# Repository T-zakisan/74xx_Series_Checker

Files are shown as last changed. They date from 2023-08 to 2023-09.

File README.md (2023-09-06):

# 74xx Series Checker
汎用ロジックIC（以降74シリーズ）の刻印が見えづらくて、どの74シリーズか判別がつかなくなることがある。  
場合によっては、配線ミスや足の欠落などにより動作しない場合もある。  
（※コレはこれで、動作不良部位を見出す訓練にもなるが、初期ではシナリオ通りの動作であった方が良い）  
それらのトラブルを回避し、刻印を読むことを目的とせず、実習を通じて論理的思考に意識を寄せたい。  

そこで、74シリーズの判定と各ビットの動作是非を表示するガジェットをArduino MicroProで作製していた。  
しかし、Arduino系は、コスト高・ソースコードの管理がメンドい（こういうところで管理すればいいだけだが、作った勢いで満足してしまいソースコードをなくしてしまった）ため、**RP2040**系に移植することにした。  
また、今回使用したマイコンの端子は、**USB Type-C**であることから、将来的なケーブル問題の懸念も解消しやすいと思う。



## 動作しているの様子
７４シリーズをＩＣソケットにセットし、マイコンのリセットボタンを押すことでロジックＩＣの種類がＬＣＤに表示される（NANDの場合：`00 NAND`）。  
機能しているビットは、そのナンバーが表示される（1-4番目のビットが機能している場合：`1234__/4`）。  
あるビットが機能していない場合や足が折れている場合は、`x`が表示される（3番目が機能していない場合：`12x4__/4`）。
対応していないロジックＩＣやロジックＩＣをセットしていない場合は、`UnKnown！`と表示される。  

https://github.com/T-zakisan/74xx_Series_Checker/assets/43605763/a2278c76-78e3-49d2-b7b0-828096098356

## 判定に対応しているロジックＩＣ
ここで対応する74シリーズは、以下とものとしている。  
また、14ピンに限る。
| 型番 | ロジック名 |
|:----:|----|
| 7400 | NAND |
| 7402 | NOR |
| 7404 | NOT |
| 7408 | AND |
| 7432 | OR |
| 7486 | Ex-OR |

## 表示の意味
液晶ディスプレイに以下の内容を表示する

| 項目名 | 例 |
|:----:|:----|
| 型番下２桁 | 74xxのxxの部分　NANDなら**00** |
| ロジック名 | NAND、ORなど |
| 可動ビット | NOTなら1-6、それ以外なら1-4　（不良はx） |
| 総ビット数 | NOTなら6、それ以外なら4 |

# 作成方法
## パーツリスト
| パーツ名 | 備考 |
|:----|:----|
| [RP2040マイコンボードキット](https://akizukidenshi.com/catalog/g/gK-17542/) | [CirCuitPythonのファームウェアを書き込むこと](https://circuitpython.org/board/raspberry_pi_pico/) |
| [ゼロプレッシャーＩＣソケット 14P](https://akizukidenshi.com/catalog/g/gP-12073/) ||
| [Ｉ２Ｃ接続小型ＬＣＤモジュール（8×2行）ピッチ変換キット](https://akizukidenshi.com/catalog/g/gK-06795/) ||
| [角型ランド両面スルーホールガラスコンポジット・ユニバーサル基板 Cタイプ(72×47mm)](https://akizukidenshi.com/catalog/g/gP-09747/) ||
| ネジ　M3xN10mm | 4 |
| ナット　M3 | 4 |
| ネジ　M2x10mm | 2 |
| ナット　M2 | 2 |
| アクリル板 | 2mm |
| ジャンパ線 | 適当 |

## アサイン
下表のアサインに従い配線を施す。  
ちなみに配線の取り回しの関係からGPIOで`GND`や`Vcc(3.3V)`を得ているが、マイコンオンボード上のソレを利用して問題ない。  
独自にアサインを変更した場合は、上記ソースコード(`code.py`)を書き換えること！

| マイコン端子 | パーツ端子 | 備考|
|:----:|:----|:----|
| 0 | LCD (Vcc) |  |
| 1 | LCD, Sw (GND) |  |
| 2 | 74シリーズ (4) | In / Output |
| 3 | 74シリーズ (1) | In / Output |
| 4 | 74シリーズ (2) | In / Output |
| 5 | 74シリーズ (3) | In / Output |
| 6 | 74シリーズ (14) | Vcc |
| 7 | 74シリーズ (13) | In / Output |
| 8 | 74シリーズ (12) | In / Output |
| 9 | 74シリーズ (11) | In / Output |
| 10 | 74シリーズ (10) | In / Output |
| 11 | 74シリーズ (9) | In / Output |
| 12 | 74シリーズ (8) | In / Output |
| 13 | 74シリーズ (5) | In / Output |
| 14 | 74シリーズ (6) | In / Output |
| 15 | 74シリーズ (7) | GND |
| 26 | LCD (SDA) |  |
| 27 | LCD (SCL) |  |
| 28 | SW (+) |  |



## 必須ライブラリ
| ライブラリ名 | 備考|
|:----|:----|
| st7032i.py | [LCDで使用](https://gist.github.com/boochow/6ffd0c939abbcc1a9c62bf6ab6b60cef#file-st7032i-py) |

## プログラム
1. マイコンに[ファームウェア](https://circuitpython.org/board/raspberry_pi_pico/)を書き込む
   - Pico用のファームウェアで問題ない
   - 書き込み方は、[ココ](https://learn.adafruit.com/welcome-to-circuitpython/installing-circuitpython)を見るか、`CirCuitPython ファームウェア 書き込み方法` でググると日本語のドキュメントがヒットする
2. 上記のライブラリ`st7032i.py`を`マイコン内の/lib`に保存
3. 上記の `code.py` をマイコンに保存

## ケース
必要に応じて、上記の3Dプリンタ用のファイル(.STL)とレーザー加工用ファイル(.DXF、.SVG)を用いてケースを作成する

| ファイル種 | 備考|
|:----|:----|
| STL | ３Ｄプリンタで印刷 |
| DXF | レーザー加工機でアクリル板（２ｍｍ）を切断・彫刻 |
| SVG | 　〃　 |

3Dモデル

# 使用方法
1. ＩＣソケットのバーを上げる
2. ＩＣソケットに７４シリーズを装着
   - ＩＣソケットのバー側が**ロジックＩＣの欠け**のある向きにすること！
3. ボタンを押す　　以上

# 反省
当初マイコンオンボードにある***RUN***ボタンを押すことで、ロジックＩＣの判定を行っていた。  
しかし、CirCuitPythonは起動にやや時間がかかるため、***RUN***ボタンを押してから、ロジックＩＣの判定までにタイムラグがあった。  
そこで、別途タクトスイッチを追加し、そのスイッチを押したときに判定することで、再起動を回避した。  
また、スイッチを押すまでは、[Alarm](**https://docs.circuitpython.org/en/latest/shared-bindings/alarm/index.html**)(**light sleep**)を利用することでプログラムを停止させ、消費電力を低減させている。  

念のため、それぞれの動作方法によるソースコードやケースデータ(.STL, .SVG)を置いておく。   
ディレクトリ名は、以下の通りとする。

| 動作方法 | ディレクトリ名 |
|:----|:----|
| Runスイッチ | RunSw |
| タクトスイッチ | ReLoadSw |

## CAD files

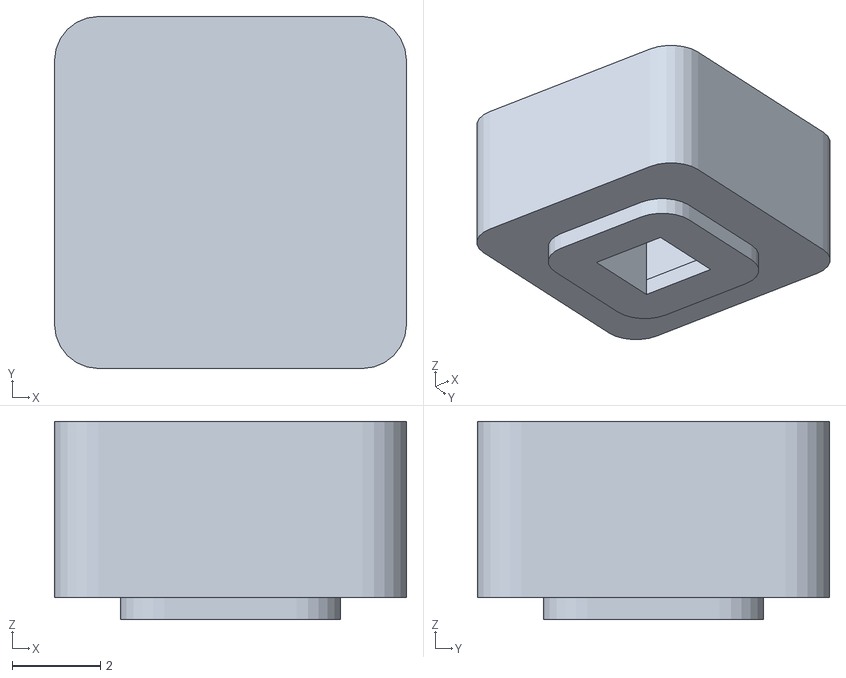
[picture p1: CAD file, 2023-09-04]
ReLoadSW/3Dプリンタ_ボタン.stl
8.00 x 8.00 x 4.50

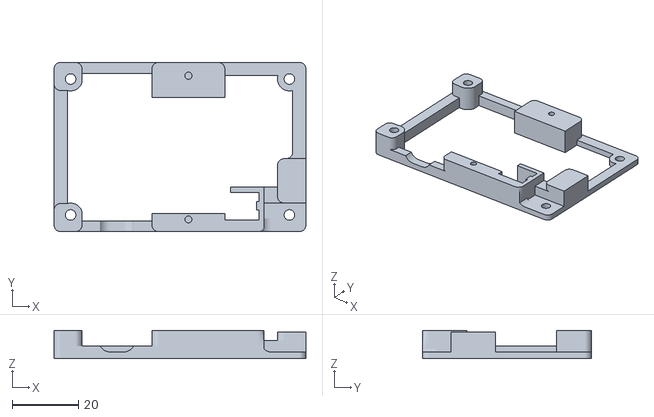
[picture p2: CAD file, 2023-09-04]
ReLoadSW/3Dプリンタ_中.stl
76.0 x 51.0 x 8.50

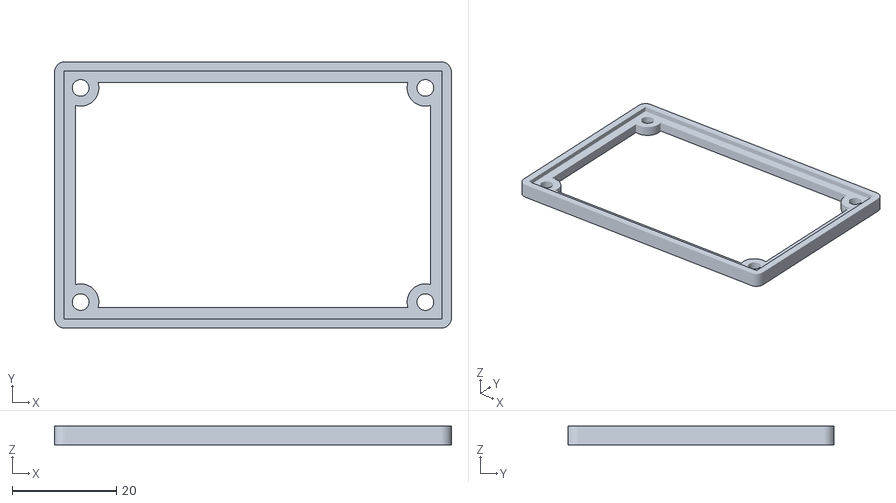
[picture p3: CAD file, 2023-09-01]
ReLoadSW/3Dプリンタ_下.stl
76.0 x 51.0 x 3.60

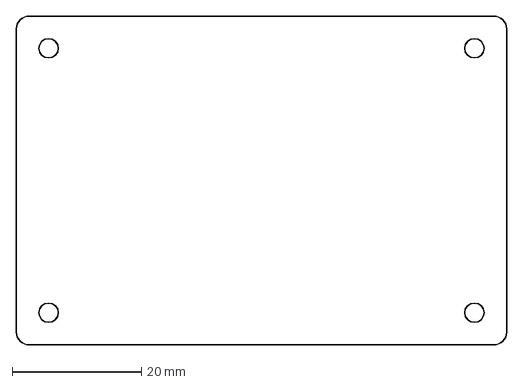
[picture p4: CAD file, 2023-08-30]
ReLoadSW/レーザー加工用_下カバー.dxf
76.0 x 51.0 mm

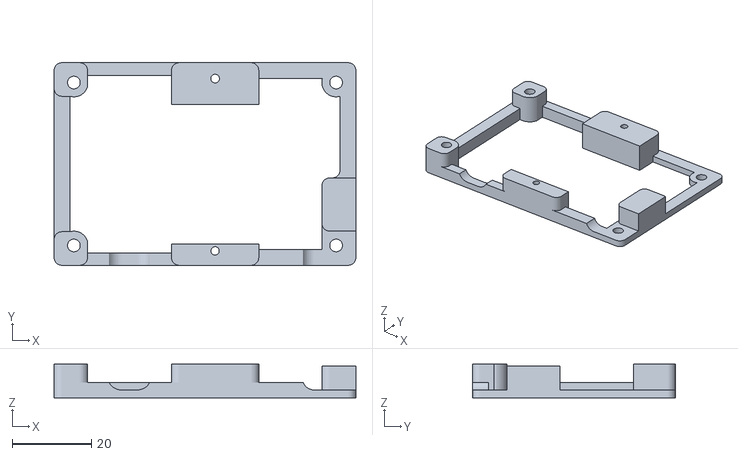
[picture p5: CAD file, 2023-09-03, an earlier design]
RunSw/3Dプリンタ_中.stl
76.0 x 51.0 x 8.50

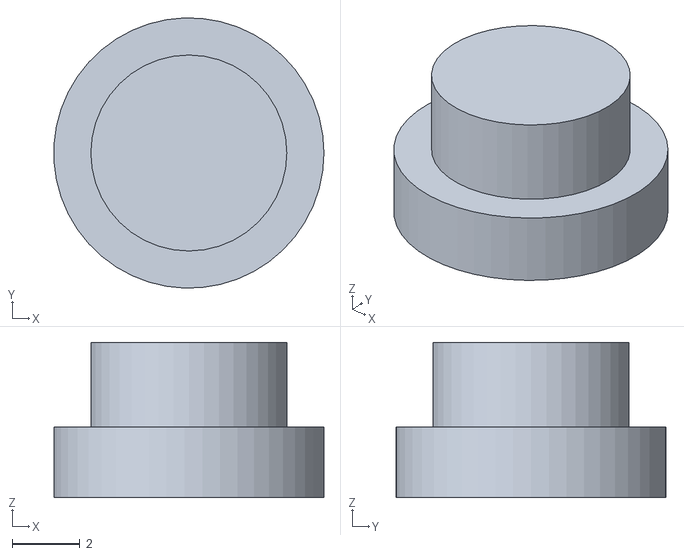
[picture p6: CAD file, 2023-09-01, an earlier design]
RunSw/3Dプリンタ_ボタン.stl
7.99 x 8.00 x 4.60

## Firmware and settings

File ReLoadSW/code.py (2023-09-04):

"""
74シリーズ(14ピン)の確認プログラム(CircuitPython)
"""

import board, digitalio, busio, alarm, time
from ST7032i import ST7032i


### 初期設定 ############################################################
PRINTFLAG = False # デバッグ用のprint　通常Flase

# 入出力     0 3.3V     1 GND      2 3.3V     3 GND 
myPinFix = ( board.GP0, board.GP1, board.GP6, board.GP15 )
myPinsFix = []
for ii, pin in enumerate( myPinFix ) :		# enumerate(添字)込みの繰り返し
	tmp_pin = digitalio.DigitalInOut( pin )	# 端子の指定
	tmp_pin.direction = digitalio.Direction.OUTPUT	# 出力
	myPinsFix.append( tmp_pin )						# リスト追加
	if ii % 2 == 0 : myPinsFix[ii].value = True		# 3.3V
	else           : myPinsFix[ii].value = False	# GND


# LCD（i2C）の設定
i2c = busio.I2C( board.GP27, board.GP26 )	# 端子指定
while not i2c.try_lock() : pass				# これないと動かない！
i2c.scan()									# アドレス
lcd = ST7032i( i2c )						# LCDに渡す
lcd.set_entry_mode( False, False )			# 　動作モード
lcd.set_contrast( 3 )						# 　明るさ
lcd.clear()									#	とりあえず初期化



# 入力パターン
myINPUT  = ( ( 0, 0 ),
	    	 ( 0, 1 ),
			 ( 1, 0 ),
			 ( 1, 1 ) )
# 出力パターン
myOUTPUT = ( ( 1, 1, 1, 0 ),
			 ( 1, 0, 0, 0 ),
			 ( 1, 0 ),
			 ( 0, 0, 0, 1 ),
		 	 ( 0, 1, 1, 1 ),
		 	 ( 0, 1, 1, 0 ) )


# 74シリーズ(14ピン) 1:In	0:Out
#          Num   Name    1   2   3   4   5   6   8   9  10  11  12  13
IC = ( 	( "00", "NAND",  1,  1,  0,  1,  1,  0,  0,  1,  1,  0,  1,  1 ),
    	( "02", "NOR",   0,  1,  1,  0,  1,  1,  1,  1,  0,  1,  1,  0 ),
	 	( "04", "NOT",   1,  0,  1,  0,  1,  0,  0,  1,  0,  1,  0,  1 ),
	 	( "08", "AND",   1,  1,  0,  1,  1,  0,  0,  1,  1,  0,  1,  1 ),
	 	( "32", "OR",    1,  1,  0,  1,  1,  0,  0,  1,  1,  0,  1,  1 ),
	 	( "86", "Ex-OR", 1,  1,  0,  1,  1,  0,  0,  1,  1,  0,  1,  1 )
	)

# 各ICの真理値表一致数 [IC数][0:真理値表適合数  1:稼働状態]
NumMatch = [ [ 0, "" ] for ii in range( len( IC ) ) ]
#         3 IC-1      4 IC-2      5 IC-3      6 IC-4     7 IC-5      8 IC-6
myPin = ( board.GP3,  board.GP4,  board.GP5,  board.GP2, board.GP13, board.GP14,
#         9 IC-8      10 IC-9     11 IC-10    12 IC-11   13 IC-12    14 IC-13
		  board.GP12, board.GP11, board.GP10, board.GP9, board.GP8,  board.GP7 )
myPins = []
for ii in myPin :
	tmp = digitalio.DigitalInOut( ii )
	tmp.direction.OUTPUT	# とりあえず出力モードで格納
	myPins.append( tmp )	# リストに追加



def myJudge() :
	for ii, ic in enumerate( IC ) :	# ロジックIC種で繰り返し
		for jj, io in enumerate( ic ) : 
			if   jj==0 : myID = io		# ロジックICのID（etc：NAND=00）
			elif jj==1 : myName = io	# 　　〃　　の名前
			elif jj>=2 :
				# 入出力の再設定
				if   io==0 : myPins[jj-2].switch_to_input( digitalio.Pull.UP )		# 入力（プルアップ）
				elif io==1 : myPins[jj-2].direction = digitalio.Direction.OUTPUT	# 出力

		# ICの入出力関係の確認(真理値表との比較)
		#  Case NOT ※I/Oのassignが異なる
		if myName=="NOT" :
			for icNum in range( 0, 11, 2 ) :
				# 真理値表との比較
				NumMatch[ii][0] = 0
				for jj in range( 2 ) :
					if icNum<6 :	# 前半
						myPins[ icNum+0 ].value = myINPUT[jj][1] # 入力
						if myPins[ icNum+1 ].value==myOUTPUT[ii][jj] : NumMatch[ii][0] += 1 # 真理値表との比較
					else : 			# 後半
						myPins[ icNum+1 ].value = myINPUT[jj][1] # 入力
						if myPins[ icNum+0 ].value==myOUTPUT[ii][jj] : NumMatch[ii][0] += 1 # 真理値表との比較

				# 表示用テキストの生成
				if NumMatch[ii][0]==2	: NumMatch[ii][1] += str( icNum//2 + 1 ) 	# ok
				else 					: NumMatch[ii][1] += str( "x" )				# NG
			
			if NumMatch[ii][1].count( "x" ) == 6: NumMatch[ii][0] = -1
			NumMatch[ii][1] += "/6"
			if PRINTFLAG==True : print( myID + "(", myName ,")\t : " + NumMatch[ii][1] )
		

		#  Case NOR ※I/Oのassignが異なる
		elif myName=="NOR" :
			for icNum in range( 0, 11, 3 ) :
				# 真理値表との比較
				NumMatch[ii][0] = 0
				for jj in range( 4 ) :
					if icNum<6 :	# 前半
						myPins[ icNum+2 ].value = myINPUT[jj][0] # 入力
						myPins[ icNum+1 ].value = myINPUT[jj][1] # 入力
						if myPins[ icNum+0 ].value==myOUTPUT[ii][jj] : NumMatch[ii][0] += 1 # 真理値表との比較
					else :			# 後半
						myPins[ icNum+0 ].value = myINPUT[jj][0] # 入力
						myPins[ icNum+1 ].value = myINPUT[jj][1] # 入力
						if myPins[ icNum+2 ].value==myOUTPUT[ii][jj] : NumMatch[ii][0] += 1 # 真理値表との比較
				
				# 表示用テキストの生成
				if NumMatch[ii][0]==4	: NumMatch[ii][1] += str( icNum//3 + 1 ) 	# ok
				else 					: NumMatch[ii][1] += str( "x" )				# NG
			
			if NumMatch[ii][1].count( "x" )==4 : NumMatch[ii][0] = -1
			NumMatch[ii][1] += "__/4"
			if PRINTFLAG==True : print( myID + "(", myName ,")\t : " + NumMatch[ii][1] )


		# Case OtherIC
		else :
			tmpTxt = ""
			for icNum in range( 0, 11, 3 ) :
				# 真理値表との比較
				NumMatch[ii][0] = 0
				for jj in range( 4 ) :
					if icNum<6 :	# 前半
						myPins[ icNum+0 ].value = myINPUT[jj][0] # 入力
						myPins[ icNum+1 ].value = myINPUT[jj][1] # 入力
						if myPins[ icNum+2 ].value==myOUTPUT[ii][jj] : NumMatch[ii][0] += 1 # 真理値表との比較
					else :			# 後半
						myPins[ icNum+2 ].value = myINPUT[jj][0] # 入力
						myPins[ icNum+1 ].value = myINPUT[jj][1] # 入力
						if myPins[ icNum+0 ].value==myOUTPUT[ii][jj] : NumMatch[ii][0] += 1 # 真理値表との比較

				# 表示用テキストの生成
				if NumMatch[ii][0]==4	: NumMatch[ii][1] += str( icNum//3 + 1 ) 	# ok
				else 					: NumMatch[ii][1] += str( "x" )				# NG

			if NumMatch[ii][1].count( "x" )==4 : NumMatch[ii][0] = -1
			NumMatch[ii][1] += "__/4"
			if PRINTFLAG==True : print( myID + "(", myName ,")\t : " + NumMatch[ii][1] )


	# もっとも一致したIC情報を液晶に表示
	if PRINTFLAG==True : print("------------------------------------")
	id = 0
	flag = False
	for ii, ic in enumerate( IC ) :
		if NumMatch[ii][0]!=-1 : 
			if NumMatch[id][0] <= NumMatch[ii][0] : id = ii ; flag = True

	lcd.clear()
	if flag == False :
		if PRINTFLAG==True : print( "UnKnown!" )
		lcd.set_cursor( 0, 0 ); lcd.print( 'UnKnown!' )
		lcd.set_cursor( 0, 1 ); lcd.print( '????????' )
		time.sleep( 0.5 )

	else :
		if PRINTFLAG==True : print( IC[id][0] + "(", IC[id][1] ,")\t : " + NumMatch[id][1] )
		lcd.set_cursor( 0, 0 ); lcd.print( str( IC[id][0] + " " + IC[id][1] ) )
		lcd.set_cursor( 0, 1 ); lcd.print( NumMatch[id][1] )
		time.sleep( 0.5 )

	for ii, ic in enumerate( IC ) : NumMatch[ii][1] = "" # ReSet



lcd.set_cursor( 0, 0 ); lcd.print( 'Set 74xx' )
lcd.set_cursor( 0, 1 ); lcd.print( 'Push SW!' )
while True :
	myAlarm = alarm.pin.PinAlarm( pin=board.GP28, value=False, pull=True )	# Light Sleepのトリガ（スイッチが押される）
	alarm.light_sleep_until_alarms( myAlarm )								# 
	myJudge( ) # 判定処理

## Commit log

2023-08-30 Update and rename 74シリーズチェッカー_ボタン.step to ボタン.step
    [ボタン.step]
2023-08-30 Update and rename 74シリーズチェッカー_中間.step to 3Dプリンタ用_中間.step
    [3Dプリンタ用_中間.step]
2023-08-30 Update and rename 74シリーズチェッカー_底.step to 3Dプリンタ用_底.step
    [3Dプリンタ用_底.step]
2023-08-30 Update and rename ボタン.step to 3Dプリンタ用_ボタン.step
    [3Dプリンタ用_ボタン.step]
2023-08-30 Update and rename 上カバー.dxf to レーザー加工用_上カバー.dxf
    [レーザー加工用_上カバー.dxf]
2023-08-30 Update and rename 下カバー.dxf to レーザー加工用_下カバー.dxf
    [レーザー加工用_下カバー.dxf]
2023-09-04 Update and rename code.py to ReLoadSWなし/code.py
2023-09-04 Create ReLoadSWあり
2023-09-04 Update and rename レーザー加工用_下カバー.dxf to RunSw/レーザー加工用_下カバー.dxf
    [レーザー加工用_下カバー.dxf]
